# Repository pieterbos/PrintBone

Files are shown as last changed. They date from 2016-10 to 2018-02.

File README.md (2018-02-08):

# PrintBone

A 3D printable trombone generator. You can use it to generate printable models for any trombone you like.

Currently included finished trombone designs:
- A large bore, 8.5 inch trombone. The bell fits a Bach 42 or 50 slide, or the included PVC slide.
- A small bore, 7 inch trombone. The bell fits a Conn 48h/6H or director slide, or the included carbon fiber slide

The design is fully parameterized. This means you can use the scripts to create any trombone design you want, with any bell profile. This included modern trombone bore shapes, but is flexible enough to also create baroque models

The bell takes about 15-30 hours of print time. It can most likely be printed faster with a 0.6mm or 0.8mm nozzle.
The slide takes about 8-12 hours print time.

# Current state

The large tenor and the small tenor both work well and play well enough to be used as a serious musical instrument.

A baroque trombone and alto design have been added. The designs both have some rather serious playability issues.

The master branch or at least commit a49e66a41785ac1fe58c5a61df087de6b6ca1ddf contain a fully working version. The large tenor is ready to print and small tenor could use some fixes:

Open issues before release:
- the small tenor is slightly too short, that should be easy to fix.
- Tuning on some partials on small the tenor are acceptable, but could be better.
- Still requires 200mm of print area height for the small tenor - perhaps I should cut it up differently so it can print on popular printers with 180mm height?

Wishlist:
- more designs, including some historical trombones
- a way to construct a good inner slide
- a 7 or 7.5 inch bell that prints without supports - should be very possible, looking at some existing designs

# License
PrintBone is licensed under the Creative Commons Attribution-NonCommercial-ShareAlike 4.0 International Public License.

You are free to download and print your own trombones, for non commercial use only. If you remix, transform, or build upon the material, you must distribute your contributions under the same license as the original.

For commercial use, just send a message or e-mail.

# What is it based on?

This trombone is based on the model of a trombone with bessel curves published in the PhD thesis of Alistair C.P. Braden, Bore Optimisation and Impedance Modelling of Brass Musical Instruments, University of Edinburgh, 2006.
Of course, it does not implement the optimisation algorithm, but you can use the output of such an algorithm and create a trombone with this script.
The parameters currently in place are the measurements he took. 
The thesis can be found at http://www.acoustics.ed.ac.uk/wp-content/uploads/Theses/Braden_Alistair__PhDThesis_UniversityOfEdinburgh_2006.pdf

The leadpipe design is inspired by a Conn 88H leadpipe, but not a reproduction.

# How does it look?

In silver and blue with PVC tubes slide:

Image of nearly PrintBone

# How does it play?

Like a  trombone.

It plays easily, sounds well and the partials are in tune. A short recording of both a printed bell and a regular brass bell with a metal slide is at https://soundcloud.com/pieter-bos-2013025 - can you guess which one is which?
Also on soundcloud is a work-in-progress recording of the bell with a PVC slide. Expect improvements later on as I fix some leaks in the slide.

# Can I easily modify it to another model?

You certainly can!

1. Download this code
2. Download the dependencies
3. Copy the large_tenor folder to a different one, give it a nice name
4. Edit the parameters of the .scad file according to the documentation in the file.

# Dependencies

Check the download_dependencies.sh script, it will download the list-comprehension demos, the curved pipe library and scad-utils. Run this in the library folder of your OpenSCAD installation for this to work in all cases. Alternatively, work with a release version that contains all the dependencies plus the code in one archive file.

# Usage

You can just download and print the STL files. To work with the OpenSCAD file:

Download and install the following libraries into the library folder of OpenSCAD:

https://github.com/openscad/scad-utils
https://github.com/openscad/list-comprehension-demos
http://www.thingiverse.com/thing:71464

Open large_tenor/large_tenor.scad and set the part variable to "all" to render the entire trombone.
the variables you can set are documented in that scad file.

The ```generate_trombone.sh``` script generates all the models in STL format, with many openscad instances running in parallel. It should take about 20-30 minutes at full detail.

# Instructions for building your own bell.

1. generate the test parts for all connectors and adjust clearances if they do not fit (a howto will be written later)
1. Print the STL files or generate your own STL files and print those. layer height 0.2mm produces a very nice result, you can choose to do smaller layers for the braces and tuning slide if you want smoother results.
2. use sandpaper to get any edges of all the joints/connectors
3. Check for leaks. You can use soapy water to find them. Can be fixed with superglue or perhaps heat
4. Glue the joints together. Superglue works well if you print it in PLA.
5. check connectors for leaks and fix where needed

test play the trombone. The entire range should respond evenly at all volumes. If any notes are hard to play, you probably have a leak somewhere.

# How large a printer do I need?
The current large bore model is meant to be printed on a printer that can print at least 21*22*20 centimeters. The small bore model fits on 180x180x200mm printers. It can be modified for smaller or larger printers relatively easily.

# Slide

A full PVC slide with printed parts has been made, including stockings. It works, but does not sound great, especially at lower volumes. Lubricate with slide cream, slide-o-mix or yamaha does not work well.

http://imgur.com/a/jYNtB

Also a Carbon fiber slide has been made. The design has been modified so it prints without supports. The carbon fiber slide is playable and a lot better than the pvc slide, but not great yet. To fix, a different material for the stockings is needed.
The carbon fiber outer slide also fits a Bach 42B inner slide, and works very well on that. The exceptionally light slide really makes for a different playing experience! It could be improved by finding a 14.9mm carbon fiber tube instead of 15mm one so it leaks less air.

To play with the slide design, check slide.scad and the stl files in the slide_out/ directory.

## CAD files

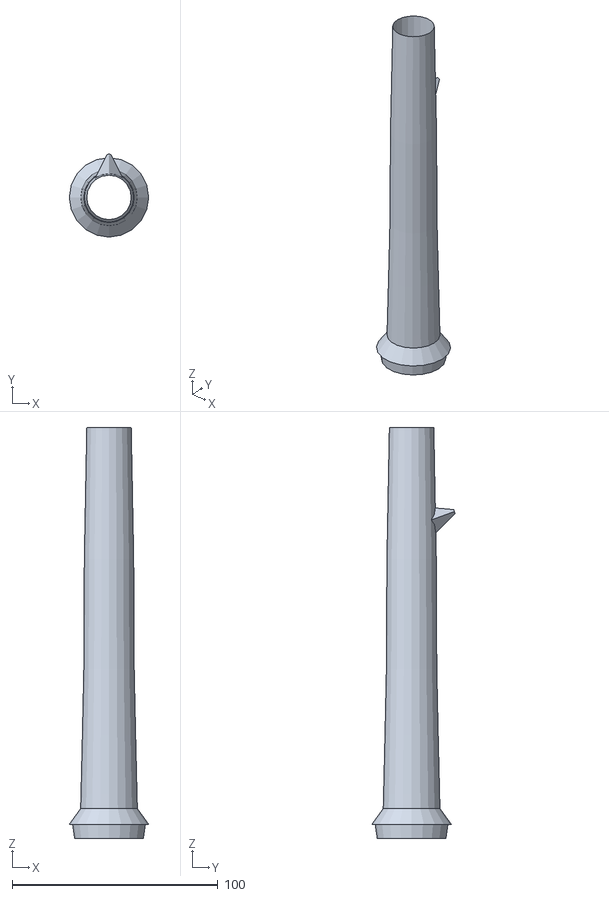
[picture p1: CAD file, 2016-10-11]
output/bell_top_2.stl
38.6 x 40.4 x 199.6

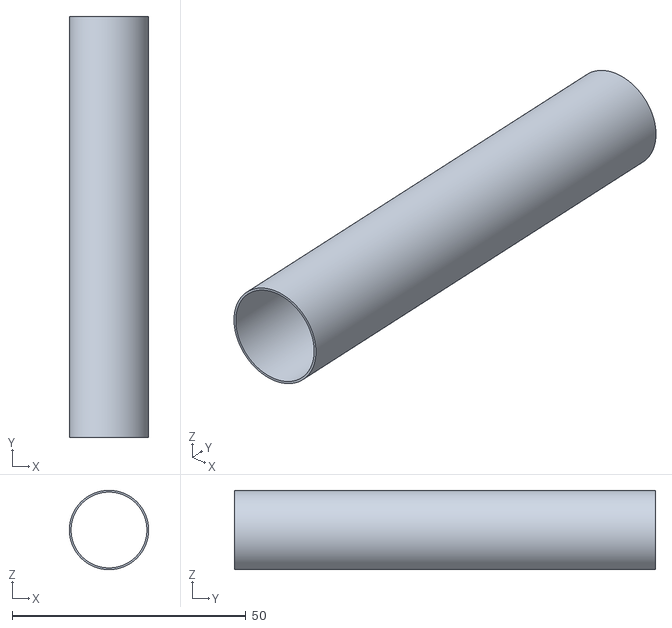
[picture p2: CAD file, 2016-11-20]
slide_out/stocking_longer.stl
16.9 x 90.0 x 16.9

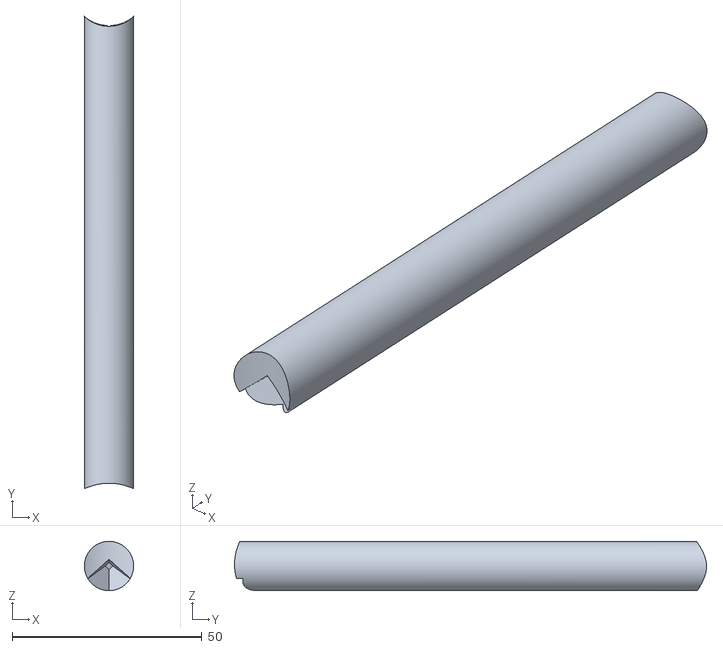
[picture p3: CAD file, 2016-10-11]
output/connection_bottom.stl
13.0 x 124.5 x 13.0

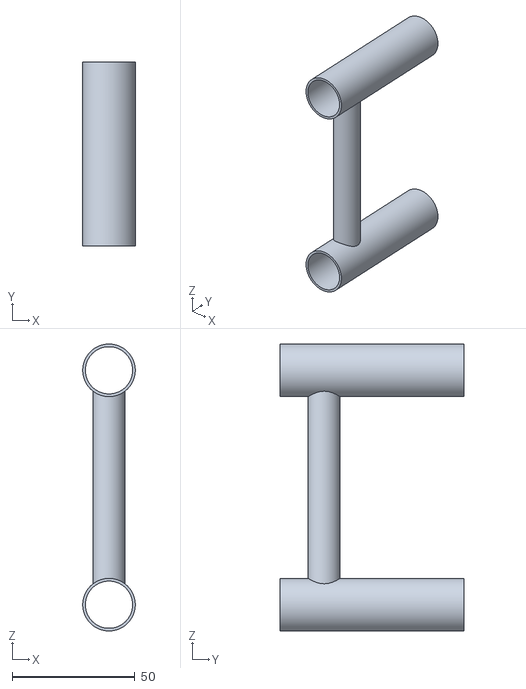
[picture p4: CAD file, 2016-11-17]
slide_out/outer_slide_grip.stl
21.4 x 75.0 x 117.0

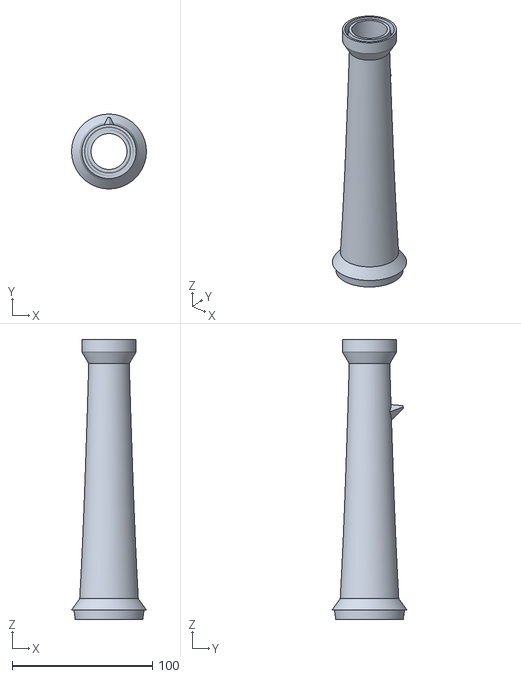
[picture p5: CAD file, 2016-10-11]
output/bell_middle_2.stl
53.3 x 53.3 x 199.7

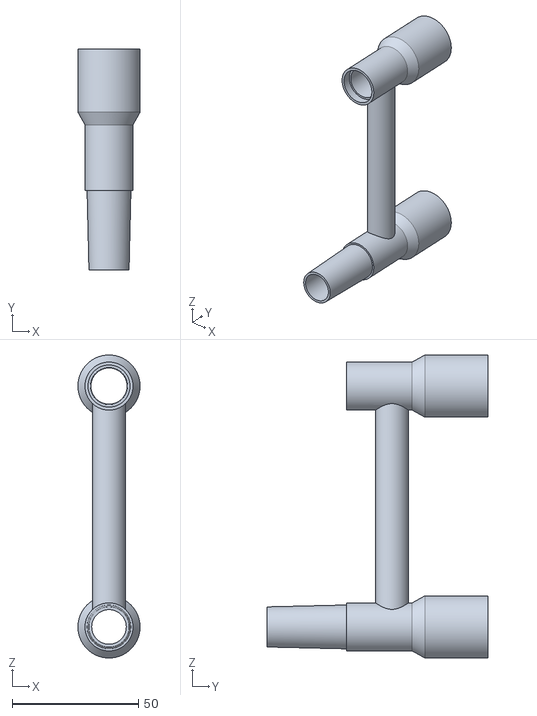
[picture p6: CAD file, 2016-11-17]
slide_out/inner_slide_grip.stl
24.7 x 87.5 x 120.2

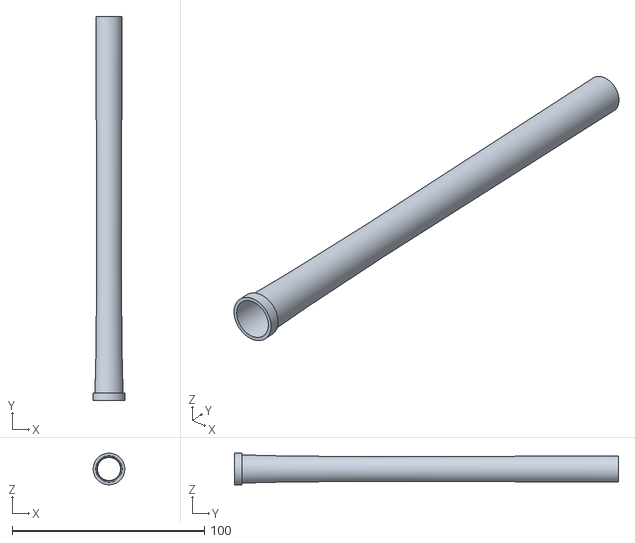
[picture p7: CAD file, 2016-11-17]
slide_out/leadpipe.stl
16.5 x 199.8 x 16.5

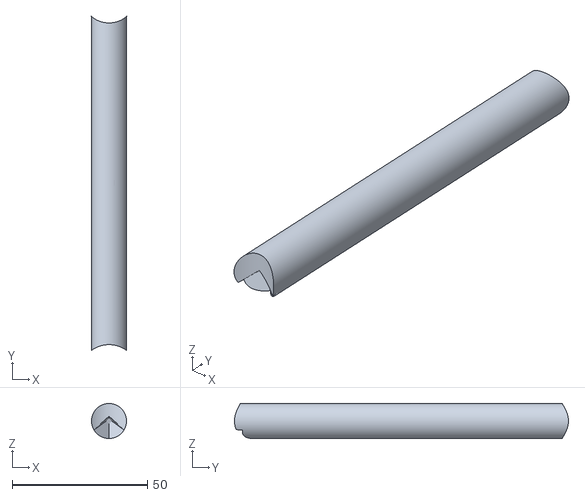
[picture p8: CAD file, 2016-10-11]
output/connection_top.stl
13.0 x 123.7 x 13.0

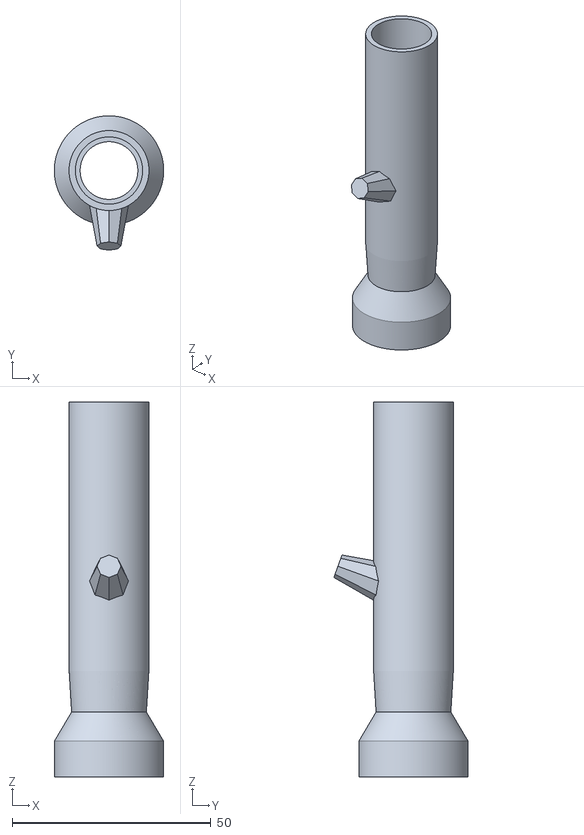
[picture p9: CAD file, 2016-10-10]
output/neckpipe_top.stl
27.5 x 33.8 x 94.3

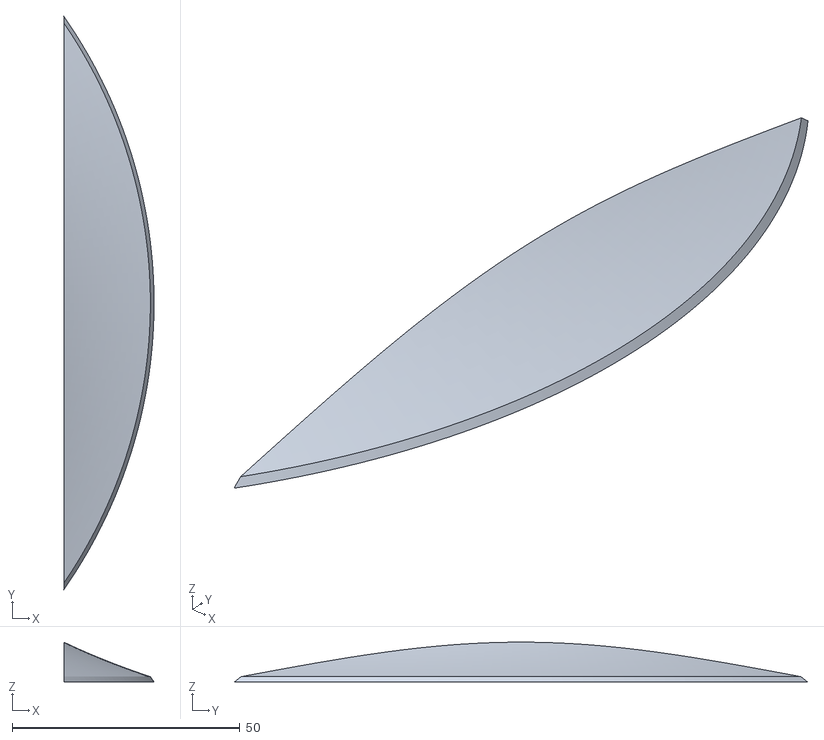
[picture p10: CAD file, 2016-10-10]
output/bell_bottom_1.stl
19.8 x 125.8 x 8.72

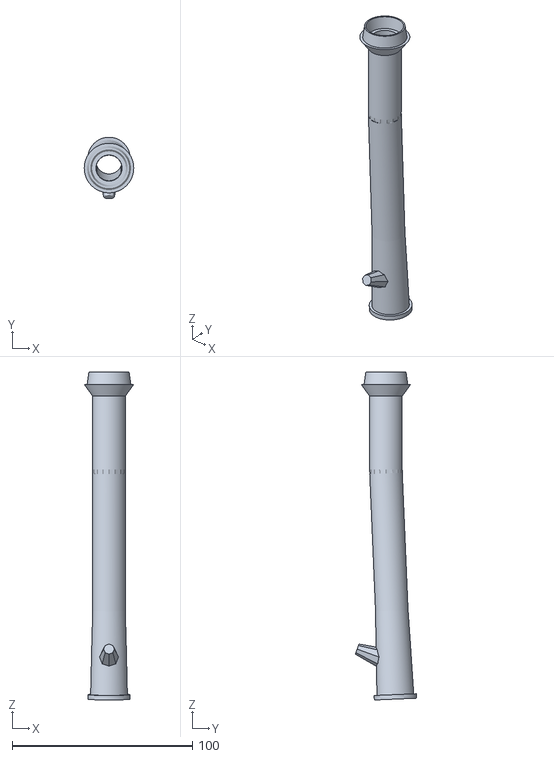
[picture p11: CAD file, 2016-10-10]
output/neckpipe_bottom.stl
27.5 x 34.1 x 182.2

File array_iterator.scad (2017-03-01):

/**
 *gives a [start:step:end] array that guarantees to include end. uglyness :)
 */
function array_iterator(start, step, end) =
    let(result = [for (i=[start:step:end]) i ]) 
    abs(result[len(result)-1] - end) < 0.000001 ? result :
    concat(
        result,
        [end]
    );
    

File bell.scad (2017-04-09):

//DO NOT RUN THIS SCRIPT, IT WILL GENERATE ERRORS!
//instead open one of the models in the sub-folders, for example large_tenor. This script will be called from there

//curve library to generate the neckpipe. Not ideal, but works for now and much easier
//to create good tubes with than with sweep() like the tuning slide.
//TODO: replace with the library newly written for this project, bent_tubes :)
use <Curved_Pipe_Library_for_OpenSCAD/curvedPipe.scad>;

use <bessel.scad>;
use <connections.scad>;


include <tuning_slide.scad>;

//the curve (not really a polygon, just a set of points for now!) of the bell
bell_profile = create_bell_profile(bell_input, steps);

//ECHO THE BELL PROFILE
//for(t= [0:len(bell_profile)-1]) {
//    echo(str(2790+bell_profile[t][1],",",bell_profile[t][0]*2,";"));
//}

//the height of the bell minus tuning slide receiver length
//TODO: get rid of the 'minus tuning slide receiver length?
total_bell_height = -sum_length(bell_input, 0); 

neckpipe_cut_height_calculated = total_bell_height + neck_pipe_length - neckpipe_cut_height;
echo(top_neckpipe_bell_connection_height - neckpipe_cut_height_calculated, "test");

top_neckpipe_bell_connection_height=neckpipe_cut_height_calculated-neckpipe_bell_connection_radius;
neckpipe_bell_connection_height = top_neckpipe_bell_connection_height+neckpipe_cut_height;
echo(neckpipe_bell_connection_height);

echo("total bell height", total_bell_height);
rotate([180,0,0]) {

    //temporary render for a test
    //translate([0,0,400])
    if(part == "tube_connector_test_top") {
        render_bell_segment(render_bottom_lip=true, render_top_lip=false, min_height=-410, max_height=-400);
    }
    if(part == "tube_connector_test_bottom") {
        render_bell_segment(render_bottom_lip=false, render_top_lip=true, min_height=-400, max_height=-380);
    }
    if(part == "slide_receiver_test") {
        slide_receiver(neckpipe_wall_thickness);
    }
    if(part == "tuning_slide_test_one") {
        tuning_slide_test_one();
    }
    if(part == "tuning_slide_test_two") {
        tuning_slide_test_two();
    }
    if(part == "connection_test_one") {
        
    }
    if(part == "connection_test_two") {
        
    }

    //solid_bell();



    //three part bell section render    
    
    if(part == "all" || part == "bell_top") {
        union() {
            render_bell_segment(render_bottom_lip=true, render_top_lip=false, min_height=third_bell_cut, max_height=second_bell_cut);
            upper_bell_connection_base();
        }
    }
    if(part == "all" || part == "bell_middle") {
        render_bell_segment(render_bottom_lip=true, render_top_lip=true, min_height=second_bell_cut, max_height=first_bell_cut,render_flat_bottom_lip=false);
          lower_bell_connection_base();
    }
    if(part == "all" || part == "bell_bottom_1") {
        intersection() {
            render_bell_bottom(two_part_cut_height);
            translate([-120+210,-120,-200])
            cube([210, 250, 200]);
        }
    }
    
    if(render_bell_flare_in_two_pieces) {
        if(part == "all" || part == "bell_bottom") {
            intersection() {
                render_bell_bottom(two_part_cut_height);
                translate([-120,-120,-200])
                cube([210, 250, 200]);
            }
        }
        if(part == "all" || part == "bell_bottom_top_part") {
            intersection() {
                render_bell_segment(render_bottom_lip=false, render_top_lip=true, min_height=first_bell_cut, max_height=two_part_cut_height,render_flat_bottom_lip=true);
                translate([-120,-120,-200])
                cube([210, 250, 200]);
            }
        }
        
    } else {    
        if(part == "all" || part == "bell_bottom") {
            if(bell_bottom_fits_on_plate) {
                render_bell_segment(render_bottom_lip=false, render_top_lip=true, min_height=first_bell_cut, max_height=0);
                if(render_bell_support) {
                    bell_support();
                }
            } else {
                intersection() {
                    render_bell_segment(render_bottom_lip=false, render_top_lip=true, min_height=first_bell_cut, max_height=0);                    
                    translate([-120,-120,-200])
                    cube([210, 250, 200]);
                }
                if(render_bell_support) {
                    bell_support();
                }
            }
        }
    }

    if(part == "all") {
        translated_tuning_slide();
    }
    if(part == "tuning_slide") {
        tuning_slide( $fn = tuning_slide_fn);
    }

    //#check_slide_clearance(neckpipe_wall_thickness);
    if(part == "all" || part == "neckpipe_bottom") {
        bottom_part_of_neckpipe(neckpipe_wall_thickness);
        if(render_neckpipe_bell_connection_with_neckpipe) {
            bell_side_neckpipe_bell_connection();
        }
    }
    if(part == "all" || part == "neckpipe_top") {
        top_part_of_neckpipe(neckpipe_wall_thickness);
        if(render_neckpipe_bell_connection_with_neckpipe) {
            tuning_slide_side_neckpipe_bell_connection();
        }
    }
    if(part == "neckpipe") {        
        rotate([-90,0,0]) {
            neckpipe(neckpipe_wall_thickness);
            bell_side_neckpipe_bell_connection();
            tuning_slide_side_neckpipe_bell_connection();
        }
    }

    if(part == "test_1") {
        intersection() {
            translate([0, 500,-150])
            rotate([-90,0,0]) {
        top_part_of_neckpipe(neckpipe_wall_thickness);

            };
                    translate([-50,12,-75])
            cube(100);
        }
    }
    
    if(part == "test_2") {
                intersection() {
                bell_side_neckpipe_bell_connection();
            translate([-50,-220,-375])
                                cube(100);
        }
    }
    
    if(!render_neckpipe_bell_connection_with_neckpipe) {
        if(part == "all" || part == "connection_bottom") {
            bell_side_neckpipe_bell_connection();
        }
        if(part == "all" || part == "connection_top") {
            tuning_slide_side_neckpipe_bell_connection();
        }
    }
}

module render_bell_bottom(height) {
   
    union() {
        render_bell_segment(render_bottom_lip=false, render_top_lip=false, min_height=height, max_height=0);
    }
}

module  tuning_slide_test_one() {
    //print only the small tuning slide peg thing
    intersection() {
        tuning_slide($fn=tuning_slide_fn);
        translate([-50,-100,0])
        cube(100);
    }
}

module  tuning_slide_test_two() {

        intersection() {
            small_tuning_slide_sleeve(neckpipe_wall_thickness);
            translate([-200,-200,-1050])
            cube(500);
        }
}    

module check_slide_clearance(wall_thickness) {
    neckpipe_implementation(wall_thickness,
			    neck_pipe_radius,
        false, check_slide_clearance=true);
}

module translated_tuning_slide() {

    translate([0,-tuning_slide_radius, total_bell_height]) {//total_bell_height-tuning_slide_small_length]) {
        rotate([270,0,0]) {
            tuning_slide($fn=tuning_slide_fn);
        }
    };
}

module slide_receiver(wall_thickness, solid = false) {

    
    if(!solid) {
        difference() {
            cylinder(r2=slide_receiver_large_radius + wall_thickness, r1=slide_receiver_small_radius +wall_thickness, h=slide_receiver_length);
            cylinder(r2=slide_receiver_large_radius, r1=slide_receiver_small_radius, h=slide_receiver_length);
        };
    } else {
            cylinder(r2=slide_receiver_large_radius + wall_thickness, r1=slide_receiver_small_radius +wall_thickness, h=slide_receiver_length);
    }


        edge_for_locknut_length= 2.5;
        outer_edge_for_locknut_length = solid ? edge_for_locknut_length +10: edge_for_locknut_length;
    edge_for_locknut_thickness = 1.5;
        translate([0,0,slide_receiver_length-edge_for_locknut_length])
        difference() {
            cylinder(r=slide_receiver_large_radius + wall_thickness+edge_for_locknut_thickness, h=outer_edge_for_locknut_length);
            cylinder(r=slide_receiver_large_radius + wall_thickness, h=edge_for_locknut_length);
        }
        if(solid) {
        }
    
        if(!solid) {
            //sleeve to make a good connection to the neckpipe - which could be less wide than this!
        
            translate([0,0,-slide_receiver_sleeve_length])
            difference() {
                cylinder(r2=slide_receiver_small_radius + wall_thickness, r1=neck_pipe_radius+wall_thickness, h=slide_receiver_sleeve_length);
                cylinder(r2=slide_receiver_small_radius, r1=neck_pipe_radius, h=slide_receiver_sleeve_length);
            }
        } else {
            //sleeve to make a good connection to the neckpipe - which could be less wide than this!
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

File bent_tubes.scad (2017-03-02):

use <scad-utils/transformations.scad>
use <list-comprehension-demos/skin.scad>

//the circle in shapes.scad is no good here, it stops one point too early
//causing a gap
function circle(r) = [for (i=[0:$fn]) let (a=i*360/$fn) r * [cos(a), sin(a)]];
    
function circle_with_hole(r_outer, r_inner) = 
    concat ( 
        circle(r_outer), reverse(circle(r_inner))
    );

function reverse(list) = [for (i = [0:len(list)-1]) list[len(list)-1-i]];


module tube(r1, r2, r_peg_1, r_peg_2, peg_th, peg_length, R, th, fn, degrees, solid)
{
    outer_r1 = r1+th;
    outer_r2 = r2 +th;
    
    outer_peg_1_r = r_peg_1 + peg_th;
    outer_peg_2_r = r_peg_2 + peg_th;
    if(solid) {
       skin(
            concat(
                //peg 1
                [
                    transform(translation([-R,0,-peg_length]), circle(outer_peg_1_r)),
                    transform(translation([-R,0, 0]), circle(outer_peg_1_r))
                ],
                //bow
                [for(i=[0:fn]) 
                transform(rotation([0,i*degrees/fn,0])*translation([-R,0,0]), 
                    concat(
                        circle(outer_r1+(outer_r2-outer_r1)/fn*i)
                    )
                )],
                
                //peg 2
                [
                    transform(rotation([0,degrees,0])*translation([-R,0, -0]), circle(outer_peg_2_r)),
                    transform(rotation([0,degrees,0])*translation([-R,0,peg_length]), circle(outer_peg_2_r))
                ]
          )
        );
    } else {

        skin(
            concat(
                //peg 1
                [
                    transform(translation([-R,0,-peg_length]), circle_with_hole(outer_peg_1_r, r_peg_1)),
                    transform(translation([-R,0, 0]), circle_with_hole(outer_peg_1_r, r_peg_1))
                ],
                //bow
                [for(i=[0:fn]) 
                transform(rotation([0,i*degrees/fn,0])*translation([-R,0,0]), 
                    concat(
                        circle_with_hole(outer_r1+(outer_r2-outer_r1)/fn*i, r1+(r2-r1)/fn*i)
                    )
                )],
                
                //peg 2
                [
                    transform(rotation([0,degrees,0])*translation([-R,0, -0]), circle_with_hole(outer_peg_2_r, r_peg_2)),
                    transform(rotation([0,degrees,0])*translation([-R,0,peg_length]), circle_with_hole(outer_peg_2_r, r_peg_2))
                ]
          )
        );
    }
       

}
pi = 3.14159265359;
bent_tube(length=500, radius1=10, radius2=25, peg1_r=10, peg2_r=25, peg_th=0.8, peg_length=100, degrees=180, wall_thickness=2.4, 
    solid=false, sweep_steps=30, $fn=64);

/**
 * Render a bent tube with tube length 'length', radius at point 0 'radius1', radius at end 'radius2'
 * number of degrees to rotate 'degrees'. The radiuses as the inner diameters!
 * if solid, renders a solid rod, with radius radius1 + wall_thickness and radius2 + wall_thickness
 * if not, renders a tube with wall thickness wall_thickness. The wall_thickness will unfortunately scale with the same scale factor as the tube radius.
 * detail can be set with sweep_steps and circle_steps
 */
module bent_tube(length, radius1, radius2, peg1_r, peg2_r, peg_th, peg_length, degrees=180, wall_thickness=1.2, solid=false, sweep_steps = 25, method="hull") {
    
    //the radius of the curve in the pipe, NOT of the tube diameters
    bend_radius = length/pi;
    
    rotate([-90,-90,0])

        tube(r1=radius1, 
            r2=radius2, 
            r_peg_1=peg1_r,
            r_peg_2=peg2_r,
            peg_th=peg_th,
            peg_length=peg_length,
            degrees=degrees,
            fn=sweep_steps,
            R=bend_radius,
            th=wall_thickness,
            solid=solid
        );
}

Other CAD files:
output/bell_top.stl
bessel.scad
connections.scad
jinbao_leadpipe.scad
large_tenor/large_tenor.scad
large_tenor/large_tenor_slide.scad
long_small_tenor_practice_mute.scad
old_tenor/old_tenor.scad
practice_mute.scad
practice_mute_trumpet.scad
renaissance_alto/bell.scad
renaissance_alto/tuning_slide.scad
slide.scad
small_tenor/slide.scad
small_tenor/small_tenor.scad
tuning_slide.scad

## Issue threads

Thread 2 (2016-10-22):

Missing dependencies: vector.scad, maths.scad and moreShapes.scad

vandenoever, 2016-10-22:
The project does not have a way to retrieve the dependencies. Some can be retrieved with this code:
```bash
# download dependencies
if [ ! -e scad-utils ]; then
    git clone https://github.com/openscad/scad-utils.git
fi
if [ ! -e list-comprehension-demos ]; then
    git clone https://github.com/openscad/list-comprehension-demos.git
fi
if [ ! -e Curved_Pipe_Library_for_OpenSCAD/curvedPipe.scad ]; then
    mkdir -p Curved_Pipe_Library_for_OpenSCAD
    wget -O Curved_Pipe_Library_for_OpenSCAD/curvedPipe.scad \
        http://www.thingiverse.com/download:170713
fi
```

That leaves `vector.scad`, `maths.scad` and `moreShapes.scad` missing.

pieterbos, 2016-10-22:
Hello Jos, thanks for the addition.

The curved pipe library dependencies are located at http://www.thingiverse.com/thing:71464/#files - that thing contains four files, not just the curved pipe library.

In the terms of your script:

```
# download dependencies
if [ ! -e scad-utils ]; then
    git clone https://github.com/openscad/scad-utils.git
fi
if [ ! -e list-comprehension-demos ]; then
    git clone https://github.com/openscad/list-comprehension-demos.git
fi
if [ ! -e Curved_Pipe_Library_for_OpenSCAD/curvedPipe.scad ]; then
    mkdir -p Curved_Pipe_Library_for_OpenSCAD
    wget -O Curved_Pipe_Library_for_OpenSCAD/curvedPipe.scad \
        http://www.thingiverse.com/download:170713
    wget -O Curved_Pipe_Library_for_OpenSCAD/moreShapes.scad \
        http://www.thingiverse.com/download:170714
    wget -O Curved_Pipe_Library_for_OpenSCAD/vector.scad \
        http://www.thingiverse.com/download:170715
    wget -O Curved_Pipe_Library_for_OpenSCAD/maths.scad \
        http://www.thingiverse.com/download:170716
fi
```

vandenoever, 2016-10-23:
Thanks! The script runs fine now.

Unfortunately OpenSCAD now crashes when opening `bell.scad` in the GUI.

After upgrading to master, `polyholes.scad` and `teardrops.scad` are missing. Where are you getting those?

pieterbos, 2016-10-23:
Check the updated readme and the first few lines of bell.scad - i restructured the project to enable multiple designs, separating the parameters from the scripts. You should now open large_tenor/large_tenor.scad instead - that should run fine. Ensure you have the most recent version because I just fixed some problems. You might want to adjust the parameters under the section called mark with DETAIL to speed up rendering, see the comments on how to do that.

I am indeed missing polyholes.scad and teardrops.scad, due to an error in one of the dependencies, i think the list comprehension demos dependency. It does not matter, as no functions or modules from these dependencies is being used.

vandenoever, 2016-10-23:
Updated to master. I can the bell parts find. The tuning_slide crashes 'openscad' and by extension 'all' even at very low detail settings.

I'm seeing some asserts in the output of the rendering command:
```bash
$ openscad -o large_tenor/output/tuning_slide.stl -Dpart=\"tuning_slide\" large_tenor/large_tenor.scad
WARNING: Can't open include file 'polyholes.scad'.
WARNING: Can't open include file 'teardrops.scad'.
PolySet has nonplanar faces. Attempting alternate construction
PolySet has nonplanar faces. Attempting alternate construction
ERROR: CGAL error in CGALUtils::applyBinaryOperator difference: CGAL ERROR: assertion violation!
Expr: itl != it->second.end()
File: /nix/store/wy4b8zwj1mvrjnk6q0ignq0dnbaqwyfy-cgal-4.7/include/CGAL/Nef_3/SNC_external_structure.h
Line: 1106
CGAL Cache insert: difference(){group(){polyhedron(points=[ (1065088 bytes)
CGAL Cache insert: group(){difference(){group(){polyhedron( (1065088 bytes)
CGAL Cache insert: group(){group(){difference(){group(){pol (1065088 bytes)
CGAL Cache insert: difference(){cylinder($fn=5,$fa=12,$fs=2 (27600 bytes)
CGAL Cache insert: group(){difference(){cylinder($fn=5,$fa= (27600 bytes)
CGAL Cache insert: multmatrix([[1,0,0,0],[0,2.22045e-16,-1, (27600 bytes)
CGAL Cache insert: multmatrix([[1,0,0,0],[0,1,0,0],[0,0,1,- (27600 bytes)
CGAL Cache insert: difference(){cylinder($fn=5,$fa=12,$fs=2 (27600 bytes)
CGAL Cache insert: group(){difference(){cylinder($fn=5,$fa= (27600 bytes)
CGAL Cache insert: multmatrix([[1,0,0,0],[0,2.22045e-16,-1, (27600 bytes)
CGAL Cache insert: multmatrix([[1,0,0,0],[0,1,0,0],[0,0,1,6 (27600 bytes)
CGAL Cache insert: group(){group(){group(){difference(){gro (1065088 bytes)
CGAL Cache insert: group(){multmatrix([[1,0,0,0],[0,1,0,0], (27600 bytes)
CGAL Cache insert: group(){multmatrix([[1,0,0,0],[0,1,0,0], (27600 bytes)
ERROR: CGAL error in CGALUtils::applyBinaryOperator union: CGAL ERROR: assertion violation!
Expr: itl != it->second.end()
File: /nix/store/wy4b8zwj1mvrjnk6q0ignq0dnbaqwyfy-cgal-4.7/include/CGAL/Nef_3/SNC_external_structure.h
Line: 1106
PolySet has nonplanar faces. Attempting alternate construction
ERROR: CGAL error in CGALUtils::applyBinaryOperator union: CGAL ERROR: assertion violation!
Expr: itl != it->second.end()
File: /nix/store/wy4b8zwj1mvrjnk6q0ignq0dnbaqwyfy-cgal-4.7/include/CGAL/Nef_3/SNC_external_structure.h
Line: 1106
CGAL Cache insert: group(){group(){group(){group(){group(){ (0 bytes)
CGAL Cache insert: difference(){multmatrix([[1,0,0,0],[0,1, (11344 bytes)
CGAL Cache hit: group(){group(){group(){group(){group(){ (0 bytes)
CGAL Cache insert: difference(){multmatrix([[1,0,0,0],[0,1, (11344 bytes)
CGAL Cache insert: group(){group(){group(){group(){differen (0 bytes)
CGAL Cache insert: group(){difference(){multmatrix([[1,0,0, (11344 bytes)
CGAL Cache insert: group(){difference(){multmatrix([[1,0,0, (11344 bytes)
CGAL Cache insert: union(){group(){group(){group(){group(){ (22592 bytes)
CGAL Cache insert: group(){union(){group(){group(){group(){ (22592 bytes)
CGAL Cache insert: group(){group(){union(){group(){group(){ (22592 bytes)
CGAL Cache insert: multmatrix([[1,0,0,0],[0,-1,-1.22465e-16 (22592 bytes)
CGAL Cache insert: group(){multmatrix([[1,0,0,0],[0,-1,-1.2 (22592 bytes)
```

pieterbos, 2016-10-23:
does it crash or just print warnings and take a very long time? I get some warnings from the sweep module that I just ignored until now because it works in the end. At high detail, rendering cost me 50 minutes on a quad core intel i7. At low detail (fn and steps at 20, angle steps at 4 degrees) maybe 5-10 minutes.  The tuning slide takes much longer because it takes a lot more polygons to render a conical bent tube smoothly than a straight one and I cannot use any of the built in modules to do so.

Preview of all parts should take maybe 1-2 seconds at low detail - try the GUI.

pieterbos, 2016-10-23:
You also have a lot of debug logging about the cache that it does not log for me. Which openscad version are you using?

vandenoever, 2016-10-24:
The crash is only in the GUI when the tuning slide is included. The program terminates with a segmentation fault. I'm using openscad 2015.03, which is the [latest release](https://github.com/openscad/openscad/releases).

I've looked into getting a backtrace with gdb, but that did not tell me much.

pieterbos, 2016-10-24:
I used to develop in 2015.03 and things worked. I then switched to the latest development version (2016.08.something for OS X at the time) because it is much faster and performance is an issue with this model because of all the round tubes.

Perhaps try the latest development version of OpenSCAD?

I know of ways to simplify and speed up the construction of the tuning slide by rendering a tube and sweeping that. Now it is a swept circle, differenced with another swept circle. OpenSCAD does not seem to like that approach very much. That would probably also solve your problems.

However with that approach the walls scale with the (conical) tuning slide, now I can keep the wall thickness constant across the model. Not that that matters much in the final model. That can of course be solved with a custom sweep module, but that is a lot of custom work just for a curved conical tube.

vandenoever, 2016-10-24:
I'll try out the development version.

Closing this issue.

Closed 2016-10-24.

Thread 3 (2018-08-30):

3D printing a leadpipe for Jinbao contrabass trombone in F

jelber2, 2018-08-30:
Hi,

I am trying 3D print a leadpipe for a Jinbao contrabass trombone in F. The bore is approximately 0.589" in the slide, so I would imagine a venturi for the leadpipe would be 0.522" or so. I edited https://github.com/pieterbos/PrintBone/blob/master/jinbao_leadpipe.scad to the following:
line 57 `leadpipe_length=199;` was changed to `leadpipe_length=222.25);`
and
line 73 `shank="small";` was changed to `shank="large";`
and
line 67 `leadpipe_venturi_radius=(10.7-0.8)/2;` was changed to `leadpipe_venturi_radius=13.26;`
but, changing the venturi to 13.26 (0.522") had an unexpected change in size

Here's with the original venturi `(10.7-0.8)/2`
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

Here's with a `13.26` venturi
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

I am guessing that this value for venturi is not a measurement in millimeters exactly, but it is used in a calculation?

Best,
Jean Elbers

pieterbos, 2018-08-30:
Hi Jean,

it should be a measurement in millimeters. However, it's a radius, not a diameter, so you should divide the value by 2.

It's very possible there are more issues with that specific script, since I've only used that file to create a specific alto leadpipe. It's only a few lines of code, so should be easy to fix, but I can't test it right now.

jelber2, 2018-08-30:
Okay, I changed the `leadpipe_venturi_radius=13.26/2;` and the `inner_slide_tube_inner_radius=14/2;`
I also changed the `leadpipe_length=200;` to fit the size of the 3D printer. This is so cool! Can't wait to try it out!
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

pieterbos, 2018-08-30:
looks good! Leadpipes seem to be the hardest part to 3d print and to get right of the entire trombone. Let me know how it works :)

jelber2, 2018-08-31:
I doubled the wall thickness to 0.8 mm. The tech said that 0.4mm came out too fragile with the 3D printer using PLA. Hope to try it out Monday.

pieterbos, 2018-08-31:
0.4 should be printable, but breaks rather easily unless you're very careful when inserting the mouthpiece. But for an alto thicker walls wasn't really an option :) 0.8 should work fine for a contrabass though

pieterbos, 2018-09-02:
Just opened the original file. Wow, I made that a bit messy :) I cleaned them up a bit, so you can download the new version. What I changed:

- wall thickness is now configurable
- mouthpiece receiver taper is more easily configured
- removed lots of old variables and code
- the length and width of the piece outside the slide is now configurable.
- the mouthpiece receiver taper starts immediately at the end of the tube, instead of directly after the bit outside of the inner slide, which makes the mouthpiece taper easier to configure

You can now set the wall thickness by changing:
```
leadpipe_wall_thickness=0.4;
```
Which will not change the mouthpiece receiver inner shape. If you make it too big, it will just not fit your inner slide at the beginning of the mouthpiece receiver. If this happens you can compensate by making the ```leadpipe_outside_slide_bit_length``` longer, it will put more of the widest parts outside of the trombone.
At the other end of the tube it will automatically compensate for inner slide tube radius.

You can change the mouthpiece taper with:
```
large_shank_large_end_diameter = 0.496*25.4;
large_shank_small_end_diameter = 0.546*25.4;
large_shank_length = 25.4;
```

That means you should be able to change everything you want to change easily now. Except for the spokes - nice idea. My leadpipes printed fine on my prusa i3 mk2 so I didn't add anything, but I did something similar for a mouthpiece: https://www.thingiverse.com/thing:1697510 . I relied on the support generation of the slicer to add a scaffolding below the horizontal disk you see there.

jelber2, 2018-09-03:
Here is the code for making the support spokes

`//Code for adding support spokes to the base of the leadpipe, cut off then sand smooth
NoSpokes = 4; // The number of support spokes
SpokesWide = 3; // The width (short side) of the arms
SpokesHigh = 2; // The height (along the Z axis) of the arms
SpokesLong = 75; // The radial length of the arms

union()
{
    for (i=[1:NoSpokes])
            rotate([0,0,360/NoSpokes*i]) // Rotate the arm after it's centered
            translate([mouthpiece_receiver_large_radius+leadpipe_wall_thickness,-SpokesWide/2,0]) // Center the arm around the X axis
            cube([SpokesLong, SpokesWide, SpokesHigh]); // Make the arm extend along the X axis

}`

jelber2, 2018-09-06:
Hmmm. The leadpipe I printed with 0.8mm walls (using the previous commit of the leadpipe code) is too stuffy due to the walls being so thick. The part of the leadpipe that goes into the inner slide is less than ~15mm in diameter (0.587"), and the inner diameter is 1.6mm less than the outer diameter simply due to the wall thickness of 0.8mm. So, I am going to try 0.4mm wall thickness.

pieterbos, 2018-09-06:
A few things that might be worth a try as well, instead of the 0.4mm wall thickness, since 0.8mm has clear advantages over 0.4 in terms of breaking easily:

- The cause for the stuffiness could just as well be something else. For example, the venturi or the shape of the leadpipe. You could try different values for the venturi diameter.
- With most 0.4mm nozzles you can print walls between 0.4-0.7mm - the flat area around the hole in the nozzle will make sure you get nice and flat lines. So you could try a 0.6mm wall thickness as a compromise. Note that this will require an extra setting in the slicer, but it's very possible.

Also now the leadpipe is just a conical piece of tubing down to the venturi, then a conical piece down to the end, plus a mouthpiece receiver. I have not checked if that's the shape a leadpipe should be. That could also be the cause of the stuffiness.

jelber2, 2018-09-06:
I am pretty sure the design is close enough to leadpipe-like in shape. I’ll try the 0.6mm walls as you suggested. I think the venturi size is okay - it translates to 13.26mm or 0.522”. As far as I know a 0.562”bore bass trombone has a 0.500 Venturi, so a 0.522” Venturi for a 0.587” bore contrabass seems reasonable.

pieterbos, 2018-09-06:
The distance of the venture from the mouthpiece receiver is also something to play with of course :)

jelber2, 2018-09-08:
In the new jinbao leadpipe scad file, the `large_shank_large_end_diameter` and `large_shank_shank_end_diameter` values need to be switched

pieterbos, 2018-09-09:
Good to hear it works. Did you sand the inside of the leadpipe, and did it make much of a difference? For mouthpieces, sanding to get a smoother surface improves the result quite a lot.

Thanks for finding that issue. I'll fix it.

jelber2, 2018-09-09:
I sanded the inside of the leadpipe where the mouthpiece goes in and that made a big difference!

jelber2, 2018-09-09:
I was playing around with the leadpipe openscad file and modified it to produce and outside shape that is cylindrical but an inside shape that is conical (like real [leadpipe](http://www.getzen.com/gazette1/imgs/oct2006/leadpipe01.gif) shape)

    union() {
        //the mouthpiece receiver
        difference() {
            union() {
                //outside shape
                cylinder(r=inner_slide_tube_inner_radius,h=mouthpiece_receiver_length);
                mouthpiece_receiver(0);
                //the extra wide bit that sticks out of the slide.
                cylinder(r=mouthpiece_receiver_large_radius+leadpipe_outside_slide_bit_wall_thickness, h=leadpipe_outside_slide_bit_length);
            }
            //inside
            mouthpiece_receiver(0);
        }
        //the rest of the leadpipe
        difference() {
            //outside
            translate([0,0,mouthpiece_receiver_length])
            cylinder(r=inner_slide_tube_inner_radius,h= leadpipe_length-mouthpiece_receiver_length);
            //inside
            leadpipe_inner_shape(0);
        }
    }
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

Not entirely convinced I implemented the code properly as the leadpipe on the left is from the original (conical design), and the one on left is with a cylindrical outer shape.

What do you think? Does this produce the same inner shape as the original code but creates an outer shape that is cylindrical? Not sure this really influences the sound much or not?

pieterbos, 2018-09-10:
The code looks right. Render doesn't really look the same indeed. You can at least get rid of the first ```mouthpiece_receiver(0)``` in the union, but that should not matter for the end result.

I've tried making the outside shape cylindrical. However, it was much easier to get a smoothly printed leadpipe with a constant wall thickness. To print a subtly variable thickness wall, your slicer needs to be able to calculate variable layer widths to make the transition from one to two walls smooth, or you end up with ridges. At least Slic3r and Cura can in fact do this, but when I tried it, it wasn't as good as just printing with a single wall in spiral vase mode. However, that was a while ago, and slicers have progressed, so it may work now.

pieterbos, 2018-09-20:
So, any news on your leadpipe project? :)

jelber2, 2018-09-20:
So, I made 3 leadpipes with 15mm gap and either .532“,.522“, or .512“ venturi. I have also made three other pipes with 0,30,and 45mm gap. All leadpipes have 0.6mm thickness with the cylindrical outerwall shape.  So far the 0.522“ venturi and 15mm gap is my favorite. I am printing the pipes at 230mm long in two pieces on a Prusa i3 MK3 with .15mm PLA layer height then using crazy glue to connect them.

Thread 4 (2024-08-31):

F attatchment

slydawg17, 2024-08-31:
I wonder if it would be possible to make a working 3d printed trombone with a F attachment. (obviously it would not be entirely 3d printed becaus you need to have some stuff to make the thing move and work)

pieterbos, 2024-09-01:
Probably, might even be possible with just a spring as the only non-printed part. But I am not actively working on this project. So if you want it, go ahead and design it :)

slydawg17, 2024-09-01:
also I would like to let you know that the files for the leadpipe (og PVC slide) and the stockings (pvc slide) are broken and wont slice correctly on your thingiverse page (I posted a comment on the page see that for more info)

slydawg17, 2024-09-01:
And another thing (back to the F attachment) how would I go about editing your model to make it. and what software would I use

pieterbos, 2024-09-02:
This has all been designed using openSCAD, which can be found at https://openscad.org/ . These openSCAD files are really a trombone generator, rather than a single design of a trombone. It can be used to generate printable trombones by specifying measurements such as bore size, length, mouthpiece shank type and bell profile. I wrote documentation on how to design your own trombone at https://github.com/pieterbos/PrintBone/wiki#how-to-create-your-own-trombone-bell-designs , including which program you need.

Please note that these instructions are there to get you up and running, and change the basic trombone shape. For more involved changes to the design, you will need programming skills.

slydawg17, 2024-09-03:
Ok thank you also sorry for bothering you about the broken file thing (I am still learning how to trouble shoot problems)  but I did fix my printing issue.  I am excited to start designing this trombone as I do have experience designing models (but only in tinker cad lol).

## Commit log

2016-09-11 First version of trombone bell section
    [bell.scad, tuning_slide.scad]
2016-09-11 Fix bell-neckpipe connection and solid bell profile
    [bell.scad, tuning_slide.scad]
2016-09-11 More bell fixes
    [bell.scad]
2016-09-11 Split neckpipe in two printable parts
    [bell.scad]
2016-09-11 Add slide clearance visualization
    [bell.scad]
2016-09-12 Better connectors on neckpipe and bell segments
    [bell.scad, tuning_slide.scad]
2016-09-12 Fix the bell segment cutting
    [bell.scad]
2016-09-13 Fixes, add part choice option
    [array_iterator.scad, bell.scad, tuning_slide.scad]
2016-09-13 Add option to switch parts
    [bell.scad]
2016-09-13 Make tuning slide detail indenpendent from $fn
    [tuning_slide.scad]
2016-09-13 Some tuning slide fixes
    [bell.scad, tuning_slide.scad]
2016-09-13 don't render tuning slide by default
    [tuning_slide.scad]
2016-09-13 Do not translate the tuning slide when only printing that
    [bell.scad, tuning_slide.scad]
2016-09-17 Add support to tuning slide so the print succeeds
    [bell.scad, tuning_slide.scad]
2016-09-17 Add different joint design
    [bell.scad, tuning_slide.scad]
2016-10-09 Lots of fixes plus generate script
    [bell.scad, tuning_slide.scad]
2016-10-10 Add changes and first STL files. They should combine to a printable trombone!
    [bell.scad, bell_bottom_1.stl, bell_middle_2.stl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]
2016-10-11 Fixes for first actual print
    [bell.scad]
2016-10-11 Fixes in generated STL files
    [bell_middle_2.stl, bell_top.stl, bell_top_2.stl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]
2016-10-12 Render tuning slide for all parts, render all parts by default
    [bell.scad]
2016-10-16 Move bent tube functionality out of tuning_slide.scad file
    Also some fixes and improvements in the bent tubes module. That can be published separately :)
    [bent_tubes.scad, tuning_slide.scad]
2016-10-16 Remove unused imports
    [tuning_slide.scad]
2016-10-16 Remove hack because of mistake in printing prototype :)
    [bell.scad]
2016-10-16 Separate bessel module from code. Small fix too.
    Solid bell rendering now takes into account wall_thickness.
    [bessel.scad]
2016-10-16 Cut the bessel-code out from bell.scad
    [bell.scad, bessel.scad]
2016-10-17 Oops, I broke the solid_bell() method, breaking much more that relied on it
    [bell.scad]
2016-10-17 Remove unused import
    [bell.scad]
2016-10-22 First commit of renaissance alto. Needs fixes in top bell part.
    [bell.scad, tuning_slide.scad]
2016-10-22 Fix script, add readme
    [bell.scad]
2016-10-22 Fix for a bug in openscad with resolution
    [array_iterator.scad, bessel.scad]
2016-10-22 Fix alto bell
    [bell.scad]
2016-10-22 WIP slide design (tubes not printed!)
    [slide.scad]
2016-10-22 Adjust fn parameters for very good output at reasonable time
    [bell.scad]
2016-10-22 Make defining a bell easier step 1
    [bell.scad]
2016-10-22 Code cleanup
    [bell.scad, bessel.scad, connections.scad]
2016-10-22 Separate parameters and implementation for large tenor trombone
    [bell.scad, bessel.scad, large_tenor.scad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]
2016-10-22 Make the bottom bell as one or two pieces configurable
    [bell.scad, large_tenor.scad]
2016-10-22 Fix comments of alto
    [bell.scad]
2016-10-22 Fix generate_trombone.sh and incorporate changes in https://github.com/pieterbos/PrintBone/pull/1
    [large_tenor.scad]
2016-10-23 Fix mistake with connectors
    [bell.scad]
2016-10-23 Attach braces optionally to neckpipe, small fixes after code restructuring
    [bell.scad, connections.scad, large_tenor.scad]
2016-10-23 Set detail to printing level intead of development level
    [large_tenor.scad]
2016-10-23 Fix small error, group detail parameters, set detail to full resolution.
    Rendering time about 50 minutes on quad-core (hyperthreading) 2013 i7 macbook
    [bell.scad, large_tenor.scad]
2016-10-24 First step towards customizer support
    [large_tenor.scad]
2016-10-30 Steps towards the design of a slide.
    [slide.scad]
2016-11-05 Design for a leadpipe that fits a jinbao alto
    [jinbao_leadpipe.scad]
2016-11-15 First slide prototype ready to print with 3/4 and 5/8 PVC pipes
    [slide.scad]
2016-11-17 Add slide stl files and update README
    [inner_slide_grip.stl, leadpipe.stl, outer_slide_grip.stl]
2016-11-20 Add slide stockings
    [slide.scad, stocking_longer.stl]
2016-12-01 First steps towards a small tenor - and outers that will fit a Bach 42B!
    [slide.scad, small_tenor.scad]
2016-12-10 work in progress on carbon fiber slide
    [slide.scad]
2017-02-25 improve cut_curve to always be at the same height
    - by refactoring radius_at_height with lookup, and using that to simplify cut_curve
    [bell.scad, bessel.scad]
2017-02-25 Add comment to debugprint function
    [bessel.scad]
2017-03-01 Add 7 inch tenor prototype, fix cut_curve, rewrite bent_tubes
    [array_iterator.scad, bell.scad, bent_tubes.scad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]
2017-03-02 Fix the bent tubes to be fast using skin
    [bent_tubes.scad]
2017-03-02 Fix tuning slide, add fancy inset
    [bent_tubes.scad, tuning_slide.scad]
2017-03-02 Small inset fixes for better printability
    [tuning_slide.scad]
2017-03-04 Try and fix tuning slide printability
    [bell.scad, small_tenor.scad, tuning_slide.scad]
2017-03-06 Make rendering time a lot shorter
    [bell.scad, small_tenor.scad, tuning_slide.scad]
2017-03-22 Fixes to small tenor, add Conn 48h/6h/director slide receiver
    [connections.scad, small_tenor.scad]
2017-03-26 automatically calculate height of connectors
    [bell.scad, small_tenor.scad]
2017-03-26 calculate tuning slide insert correctly. Next: correct length of small bore horn
    [large_tenor.scad, small_tenor.scad, tuning_slide.scad]
2017-04-09 Add a custom support option for printing the bell, hopefully working better due to bridging
    [bell.scad, large_tenor.scad, small_tenor.scad]
2017-04-16 Fixes to small slide, disable custom bell support for now
    [large_tenor.scad, slide.scad]
2017-04-17 Slide model improvements, large tenor detail settings and minor fixes
    [large_tenor.scad, slide.scad]
2017-05-14 Standalone practice mute with customizer support. Practice mute branch can be deleted :)
    [practice_mute.scad]
2017-07-01 Update practice mute with newer version
    [practice_mute.scad]
2017-07-17 Add Nuremberg 1594 copy - with some guesswork, unfortunately!
    [old_tenor.scad, tuning_slide.scad]
2018-09-02 Cleanup the jinbao leadpipe script a bit
    [jinbao_leadpipe.scad]
2018-09-09 Fix the mistake that @jelber2 found.
    [jinbao_leadpipe.scad]
2022-11-08 Fix the slide, make it easier to generate the separate parts as well
    [large_tenor_slide.scad]
2022-11-08 Fix large tenor ledpipe
    [large_tenor_slide.scad]
2024-11-05 Update practice mute with text, a fix, and the long tenor version
    [long_small_tenor_practice_mute.scad]
2024-11-05 Add trumpet practice mute scad file
    [practice_mute_trumpet.scad]
2024-11-05 Fix text alignment on side of trumpet mute
    [practice_mute_trumpet.scad]
